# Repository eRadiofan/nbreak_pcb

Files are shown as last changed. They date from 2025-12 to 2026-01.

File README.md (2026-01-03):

# nbreak_pcb

This is an Econet transceiver PCB designed for [the n-break project](https://github.com/banksy-git/nbreak-econet), using Kicad. Currently, only the [eRadiofan fork](https://github.com/eRadiofan/nbreak-econet) is compatible and tested as working with this PCB.

The board is intended to be soldered to an ESP32-C6 module, the following are know to fit:

- Waveshare ESP32-C6 Development Board
- Diymore ESP32-C6-WROOM1 Module

Many others have a suitable pinout.

The board hosts 2 MAX485 chips running at 5V with level shifters for interfacing with the ESP32-C6.

Connection is via 5-pin DIN and/or 5-pin header.

Internal/external clock selection is via the UI. There is a link for enabling on-board terminators and a jumper option for enabling selection via the UI in the future.

There is a blue LED for indication of a clock signal and a bi-colour LED for indication of transmission and reception. They are designed as 3mm through-hole types intended for poking through holes in a case (TBD).

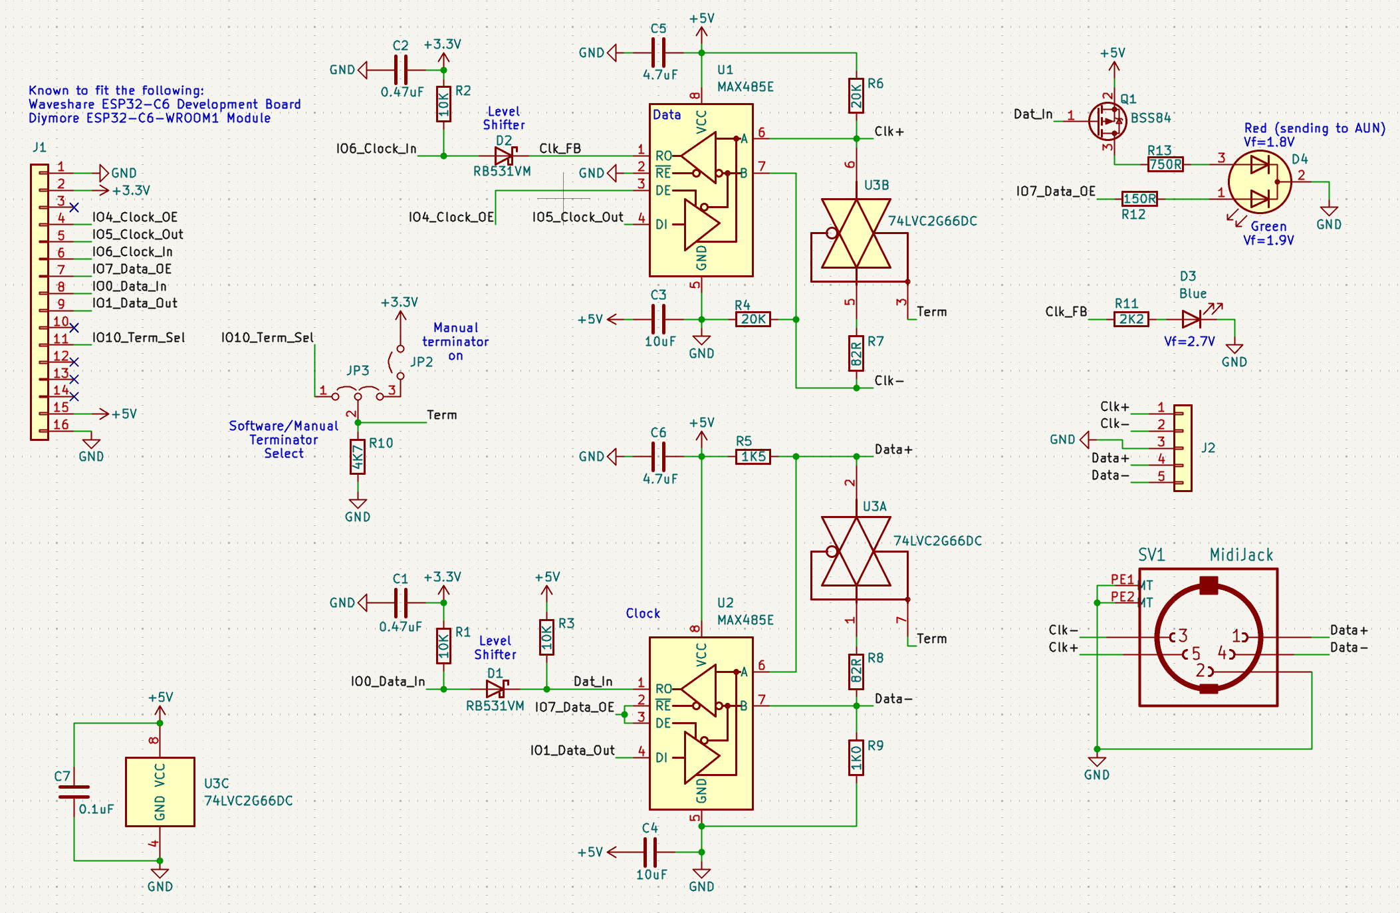
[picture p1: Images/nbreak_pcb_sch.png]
PCB schematic


The PCB is only 31mm wide and 44mm long.

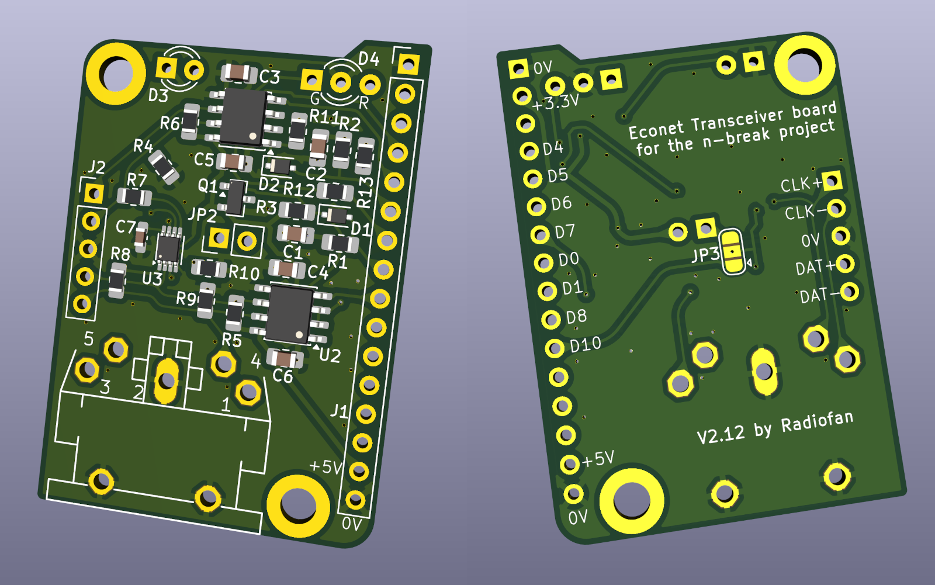
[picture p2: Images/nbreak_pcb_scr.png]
PCB screenshot


Version 1 assembled (wired direct to header) and soldered to ESP32-C6 board:

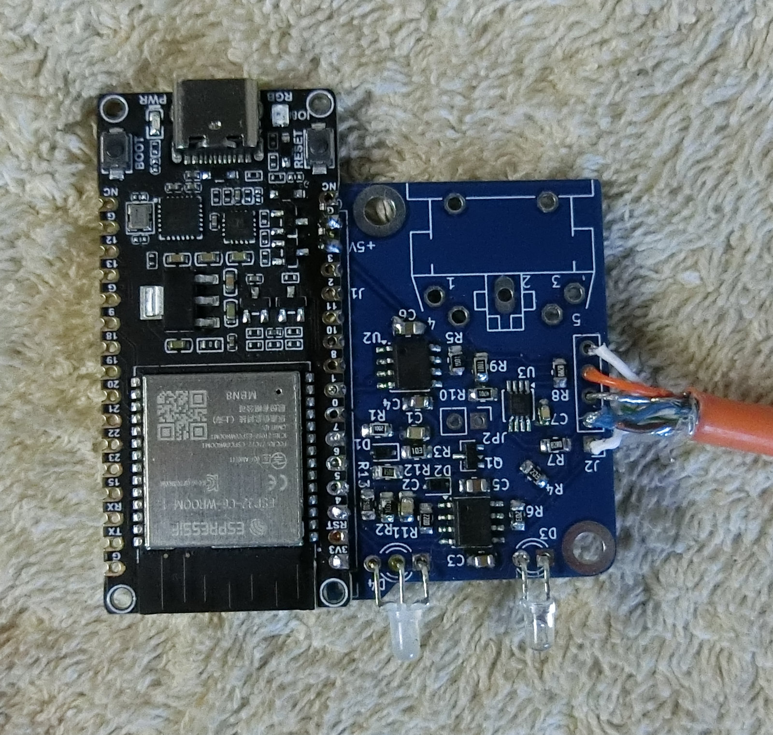
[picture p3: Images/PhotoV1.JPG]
Photo of PCB


Version 2 contains a correction to the footprint of IC U3 and has a connection to D10 instead of D8.

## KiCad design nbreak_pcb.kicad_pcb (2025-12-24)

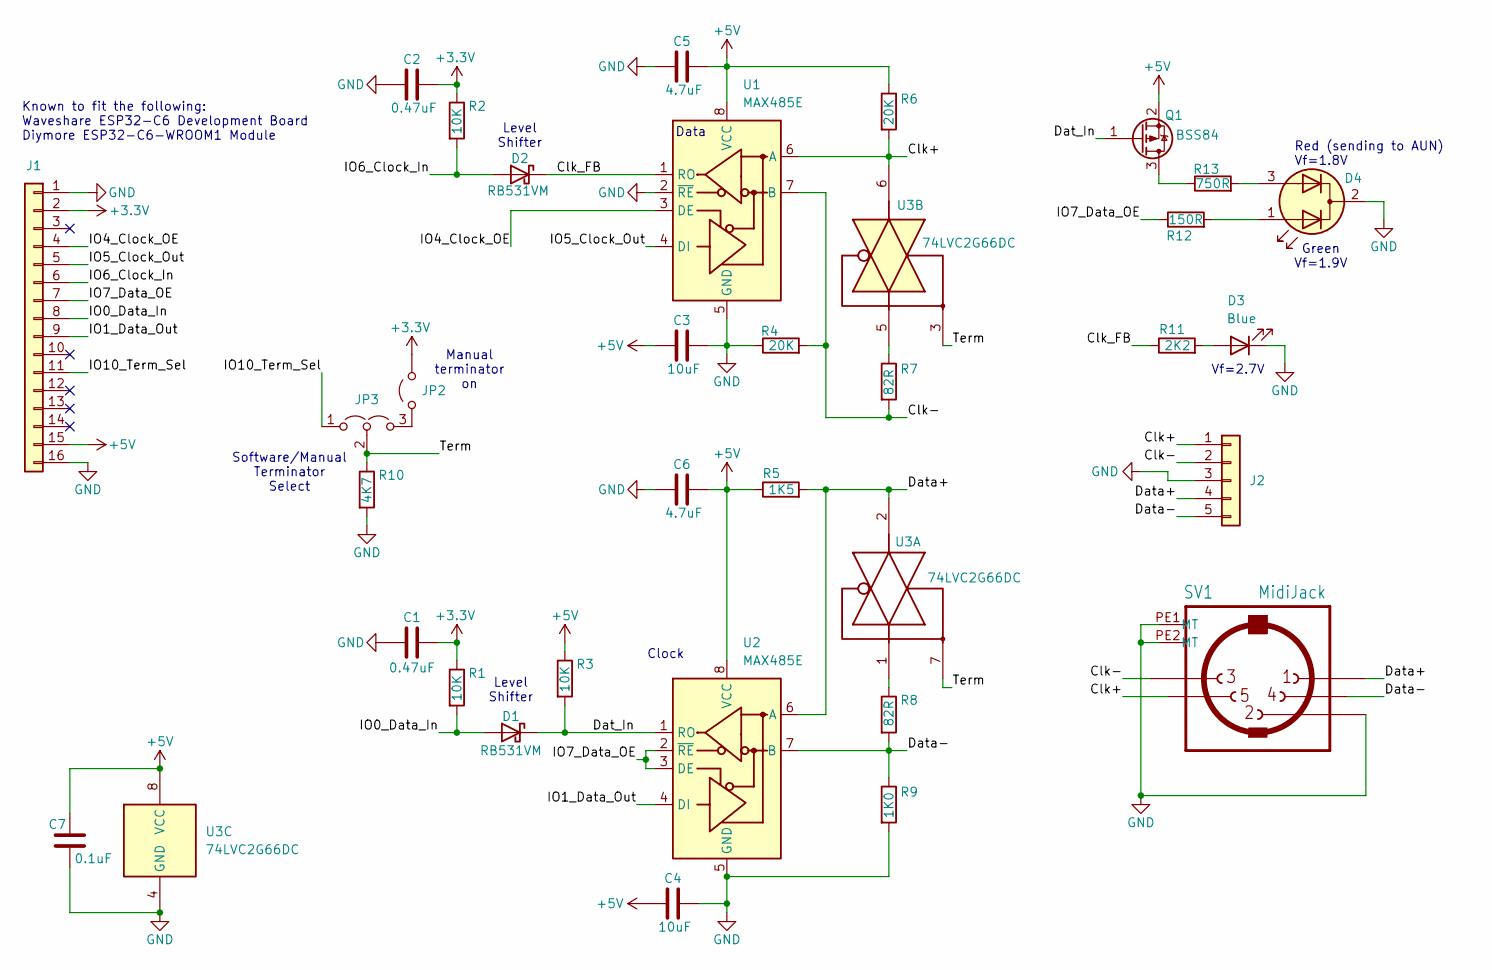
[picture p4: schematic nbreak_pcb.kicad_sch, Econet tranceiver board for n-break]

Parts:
C1, C2: 0.47uF; C_0805_2012Metric_Pad1.18x1.45mm_HandSolder
C3, C4: 10uF; C_0805_2012Metric_Pad1.18x1.45mm_HandSolder
C5, C6: 4.7uF; C_0805_2012Metric_Pad1.18x1.45mm_HandSolder
C7: 0.1uF; C_0603_1608Metric_Pad1.08x0.95mm_HandSolder
D1, D2: RB531VM; D_SOD-323F
D3: Blue; LED_D3.0mm
D4: LED_Dual_AAK; LED_D3.0mm-3
J1: Conn_01x16; PinHeader_1x16_P2.54mm_Vertical
J2: Conn_01x05; PinHeader_1x05_P2.54mm_Vertical
JP2: Jumper_2_Open; PinHeader_1x02_P2.54mm_Vertical
JP3: Jumper_3_Open; SolderJumper-3_P1.3mm_Open_RoundedPad1.0x1.5mm
Q1: BSS84; SOT-23
R1, R2, R3: 10K; R_0805_2012Metric_Pad1.20x1.40mm_HandSolder
R4, R6: 20K; R_0805_2012Metric_Pad1.20x1.40mm_HandSolder
R5: 1K5; R_0805_2012Metric_Pad1.20x1.40mm_HandSolder
R7, R8: 82R; R_0805_2012Metric_Pad1.20x1.40mm_HandSolder
R9: 1K0; R_0805_2012Metric_Pad1.20x1.40mm_HandSolder
R10: 4K7; R_0805_2012Metric_Pad1.20x1.40mm_HandSolder
R11: 2K2; R_0805_2012Metric_Pad1.20x1.40mm_HandSolder
R12: 150R; R_0805_2012Metric_Pad1.20x1.40mm_HandSolder
R13: 750R; R_0805_2012Metric_Pad1.20x1.40mm_HandSolder
SV1: MidiJack; MidiConnector
U1, U2: MAX485E; SOIC-8_3.9x4.9mm_P1.27mm
U3: 74LVC2G66DC; VSSOP-8_2.3x2mm_P0.5mm

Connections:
+3.3V: C1.2, C2.2, J1.2, JP2.2 (B), R1.1, R2.1
+5V: C3.1, C4.1, C5.2, C6.2, C7.2, J1.15, Q1.2 (S), R3.1, R5.1, R6.1, U1.8 (VCC), U2.8 (VCC), U3.8 (VCC)
/Clk+: J2.1, R6.2, SV1.5, U1.6 (A), U3.6
/Clk-: J2.2, R4.2, R7.2, SV1.3, U1.7 (B)
/Clk_FB: D2.1 (K), R11.1, U1.1 (RO)
/Dat_In: D1.1 (K), Q1.1 (G), R3.2, U2.1 (RO)
/Data+: J2.4, R5.2, SV1.1, U2.6 (A), U3.2
/Data-: J2.5, R8.2, R9.1, SV1.4, U2.7 (B)
/IO0_Data_In: D1.2 (A), J1.8, R1.2
/IO1_Data_Out: J1.9, U2.4 (DI)
/IO4_Clock_OE: J1.4, U1.3 (DE)
/IO5_Clock_Out: J1.5, U1.4 (DI)
/IO6_Clock_In: D2.2 (A), J1.6, R2.2
/IO7_Data_OE: J1.7, R12.1, U2.2 (~RE), U2.3 (DE)
/IO10_Term_Sel: J1.11, JP3.1 (A)
/Term: JP3.2 (C), R10.1, U3.3, U3.7
GND: C1.1, C2.1, C3.2, C4.2, C5.1, C6.1, C7.1, D3.1 (K), D4.2 (K), J1.1, J1.16, J2.3, R4.1, R9.2, R10.2, SV1.2, SV1.PE1 (MT), SV1.PE2 (MT), U1.2 (~RE), U1.5 (GND), U2.5 (GND), U3.4 (GND)
unnamed: D3.2 (A), R11.2
unnamed: D4.1 (A1), R12.2
unnamed: D4.3 (A2), R13.2
unnamed: JP2.1 (A), JP3.3 (B)
unnamed: Q1.3 (D), R13.1
unnamed: R7.1, U3.5
unnamed: R8.1, U3.1

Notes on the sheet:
Red (sending to AUN) Vf=1.8V
Level Shifter
Manual terminator on
Software/Manual Terminator Select
Known to fit the following: Waveshare ESP32-C6 Development Board Diymore ESP32-C6-WROOM1 Module
Clock
Data
Green Vf=1.9V
Vf=2.7V

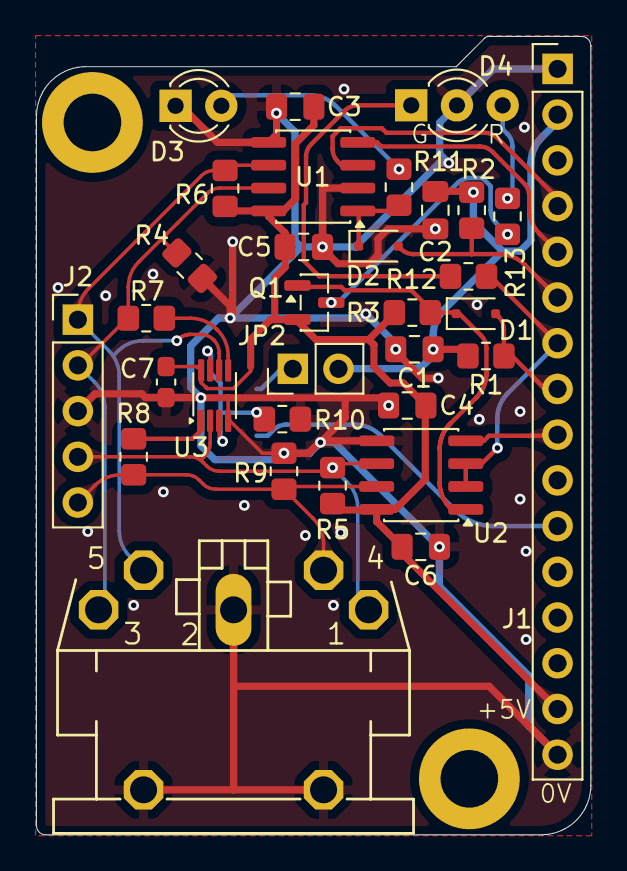
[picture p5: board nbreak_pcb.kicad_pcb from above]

Board: 2 copper layers, 30.8 x 44.4 mm, 33 parts (1 on the bottom side), 24 nets.

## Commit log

2025-12-10 Initial version
    [nbreak_pcb.kicad_pcb, nbreak_pcb.kicad_sch]
2025-12-10 Fixed data polarity at DIN socket
    [nbreak_pcb.kicad_pcb, nbreak_pcb.kicad_sch]
2025-12-10 Update schematic image following fix
2025-12-11 Simplified clock and terminator selection
    [nbreak_pcb.kicad_pcb, nbreak_pcb.kicad_sch]
2025-12-12 Added activity indicator LEDs
    [nbreak_pcb.kicad_pcb, nbreak_pcb.kicad_sch]
2025-12-24 Updates for version 2, following construction of first prototype
    [nbreak_pcb.kicad_pcb, nbreak_pcb.kicad_sch]
2026-01-03 Updates to README, images and added a photo of aseembled PCB
